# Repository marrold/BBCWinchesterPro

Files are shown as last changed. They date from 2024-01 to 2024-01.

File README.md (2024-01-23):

# BBCWinchesterPro

A PCB that combines a Raspberry Pi running [PiTubeDirect](https://github.com/hoglet67/PiTubeDirect) and a J.G Harston's [IDE Interface](https://mdfs.net/Info/Comp/BBC/IDE/), intended to emulate the 6502 2nd Processor and Winchester Hard Disk required to run a Level 3 Econet Fileserver on a BBC Micro Model B.

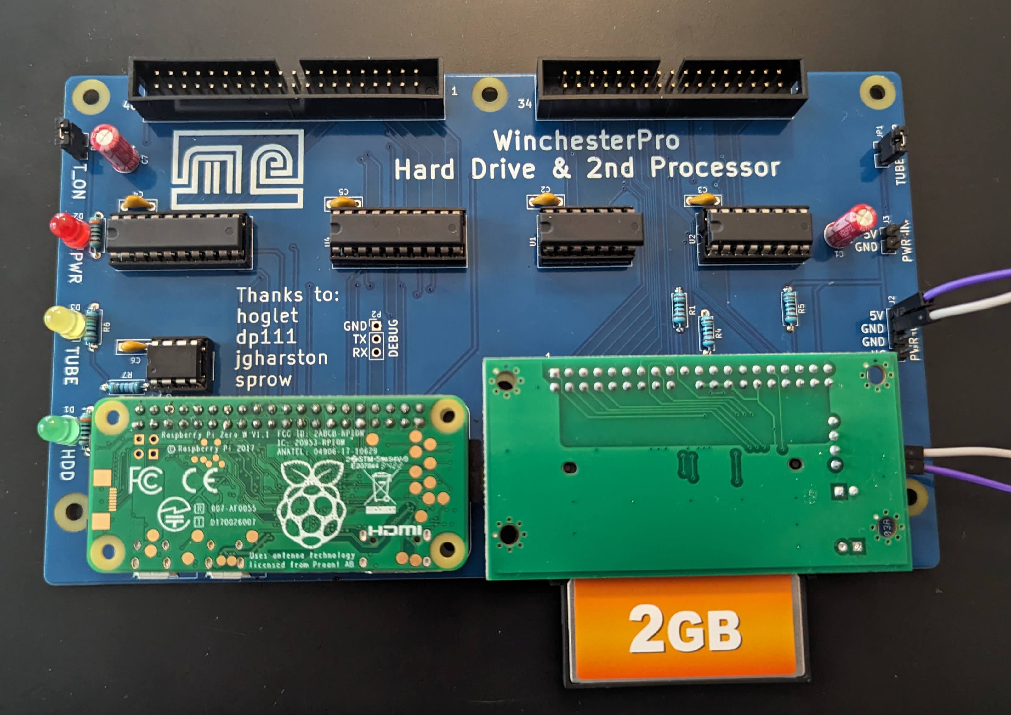
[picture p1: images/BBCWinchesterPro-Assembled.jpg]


The current revision was designed to test if the theory works rather than a finished product. The long term goal is to place it in a suitably 80's looking enclosure which will probably require some changes to the overall size and mounting holes but perhaps in the meantime the schematics and PCB will be useful to someone.

The schematic is included as a [PDF](Schematic.pdf)

## Whats the ATTiny MCU for?

PiTubeDirect *toggles* the Pi's onboard LED when the Tube is accessed, however I'd like an external LED to pulse with activity. The ATTiny detects a rising or falling edge and pulses the LED for 50ms.

To use this feature you'll need to program the ATTiny and use the [Indigo Alpha 4](https://github.com/hoglet67/PiTubeDirect/releases/tag/indigo-alpha4) revision of PiTubeDirect which supports re-mapping the activity to another GPIO.

Add the following to the end of `cmdline.txt`:
`bcm2708.disk_led_gpio=16`

This is somewhat experimental, the code is crude, and I'm not entirely sure if its detecting every edge when the Tube is at full tilt, but it makes the LED blink convincingly   so its good enough for my requirements.

If you don't want to bother with it, you can bridge pins 2 and 3 of the U5 footprint, indicated on the silkscreen.

## Usage

- It's *highly recommended* to use a 2GB CF Card as modified tools exist to deal with a disc this size
- For information on setting up and using PiTubeDirect, see the projects detailed [Wiki](https://github.com/hoglet67/PiTubeDirect/wiki)
- To use the IDE interface you'll need version [ADFS  v1.33](https://mdfs.net/System/ROMs/Filing/Disk/Acorn/ADFS133) which has been patched for IDE support.
- I also recommend using patched versions of [HDInit](https://mdfs.net/Info/Comp/BBC/IDE/HDInit) and [WFSInit](https://stardot.org.uk/forums/viewtopic.php?p=411297#p411297) that can handle larger discs.
- For instructions on formatting the CF card see the [Wiki](https://github.com/marrold/BBCWinchesterPro/wiki/Formatting-the-Hard-Disk)
- For instructions on setting up the Econet partition, also see the [Wiki](https://github.com/marrold/BBCWinchesterPro/wiki/Initialising-the-Disk-for-a-Level-3-Econet-Fileserver)

## Parts Required

- [PCI slot IDE to Compact Flash Adapter](https://www.amazon.co.uk/gp/product/B0913811PP)
- Raspberry Pi + SD Card
- 5x 0.1uF ceramic capacitors with a 5mm pitch
- 2x 22uF electrolytic capacitors with a 2mm pitch
- 3x 1k 1/4w resistors
- 3x LEDs and suitable 1/4w resistors
- 2x [SN74LVC245AN](http://d.digikey.com/dc/mn-w0iJh4uEE_bUitNCuXpPSTLmwSDrmPaa_ksuLmn07WQWvHI6vieAM8l8Rz71y9-o2iqNxD_lrRHs2f6p78UOWSMZi80Re0OX4QjTHXhzXzyCP1n-WYmlf5x2yjzHYfHzZC5O6tAVst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)
- 1x [SN74LS02N](http://d.digikey.com/dc/mn-w0iJh4uEE_bUitNCuXpPSTLmwSDrmPaa_ksuLmn07WQWvHI6vieAM8l8Rz71y9-o2iqNxD_lrRHs2f6p78bnTDQXV0_ONXEKM5iC55d-ZDkkt9n89zQITQIYKv5ImfzPp6AZ2aezEF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)
- 1x [SN74LS139AN](http://d.digikey.com/dc/mn-w0iJh4uEE_bUitNCuXpPSTLmwSDrmPaa_ksuLmn07WQWvHI6vieAM8l8Rz71y9-o2iqNxD_lrRHs2f6p78ZChZSCAtt8kdLK_f7oz0DTUWDhmkEZ-6cGHutOkHit2hcfdb0F0ck6e2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)
- 1x [ATTINY85-20PU](http://d.digikey.com/dc/mn-w0iJh4uEE_bUitNCuXpPSTLmwSDrmPaa_ksuLmn3wb489Ozp7P-auFeMYVOl116EiIEbZ38BDQy1OX_LrrLPV3Ec8LFvckgIt5WBiMOWBzA2AtKbyb9r8UKNGoR5mw2eYflZHiaYFx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)
- 2x 20 pin DIP sockets
- 1x 16 pin DIP socket
- 1x 14 pin DIP socket
- 1x 4 pin DIP socket
- 1x 40 Pin, 2.54 pitch Male Shrouded + Keyed connector
-  1x 34 Pin, 2.54 pitch  Male Shrouded + Keyed connector
- 1x 40 Pin, 2.54 pitch Female connector with key
- 1x 40 Pin, 2.54 pitch  Female connector without key. (Or get 2 of the above)
- 2.54 pitch male header pins - a few
- 2x Jumpers
- Nylon PCB standoffs - some

## Future improvements
- The Raspberry Pi SD card is blocked by the CF adapter, so upgrading PiTubeDirect requires removing the Pi entirely which isn't great. The Tube and IDE sections of the board should probably be swapped.
- The PCB was designed for a specific IDE to CompactFlash adapter which has resulted in the pin numbering being backwards, making it unsuitable for use with cables or other adapters. In a future revision I'd like to use a standard pin numbering for greater flexibility
- There's no power available on pin 20 of the IDE connector, which some CF adapters can utilise. In future revision it's probably sensible to make power available on this pin with a solder jumper to enable it.

## License

- The PCB is licensed under GPL 3.0
- The [PiTubeDirect](https://github.com/hoglet67/PiTubeDirect) interface schematic and firmware is licensed under GPL 3.0
- The [IDE interface](https://mdfs.net/Info/Comp/BBC/IDE/) was designed by J.G Harston and [sprow](http://www.sprow.co.uk/) and anyone is permitted to use the design with acknowledgement.

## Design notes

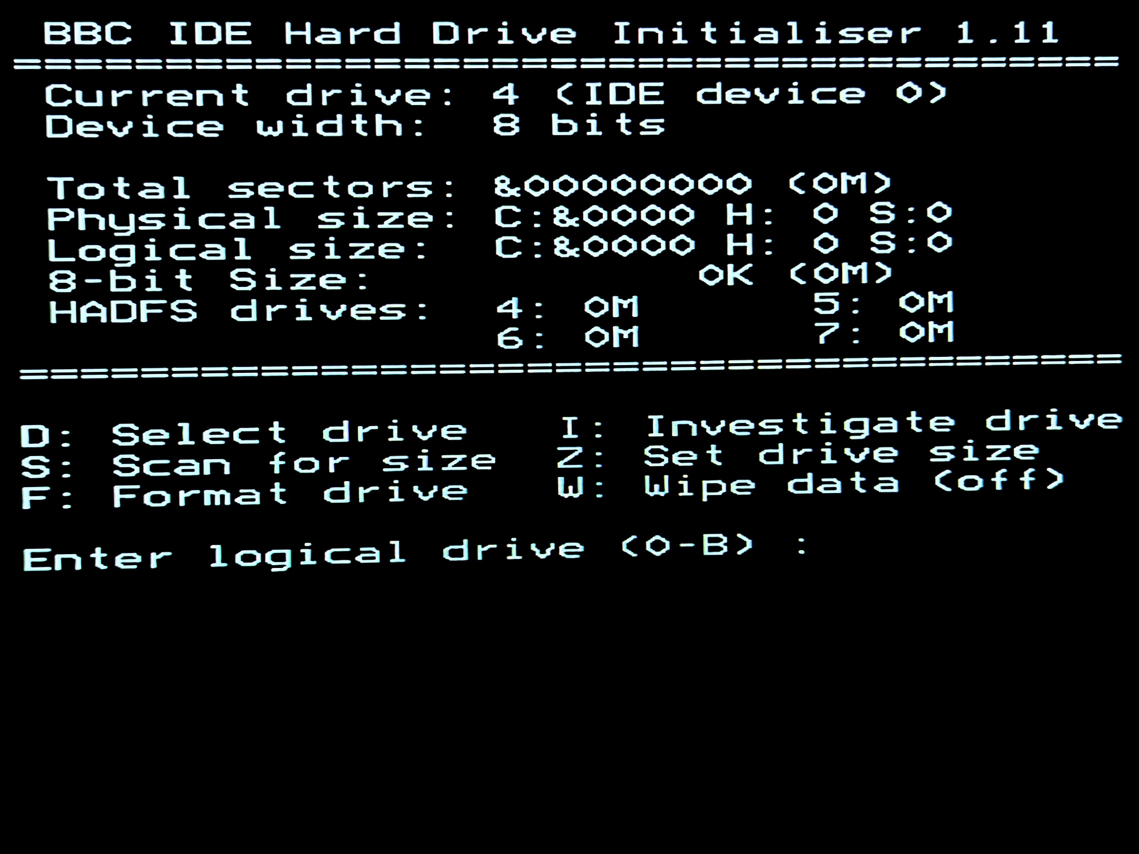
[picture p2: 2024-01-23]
images/HDINIT_DRIVE.jpg

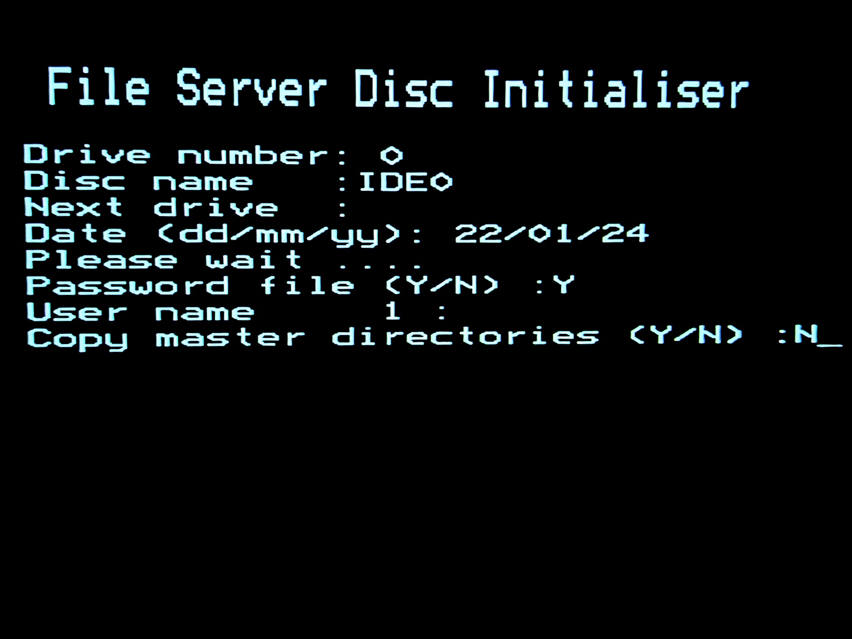
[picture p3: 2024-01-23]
images/WFSINIT_COPYMASTERDIRS.jpg

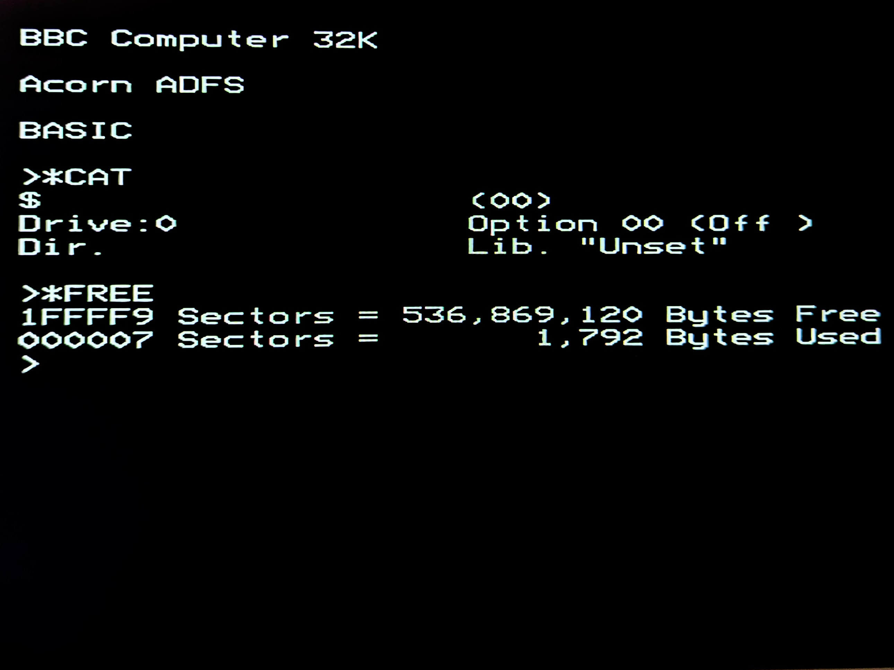
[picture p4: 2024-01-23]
images/HDINIT_FREE.jpg

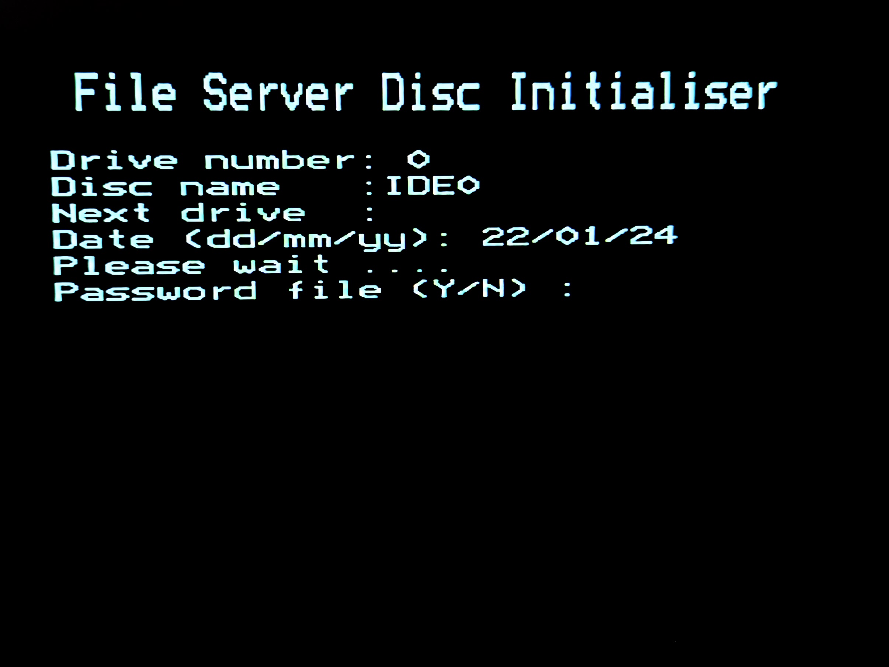
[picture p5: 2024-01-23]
images/WFSINIT_PASSWORDFILE.jpg

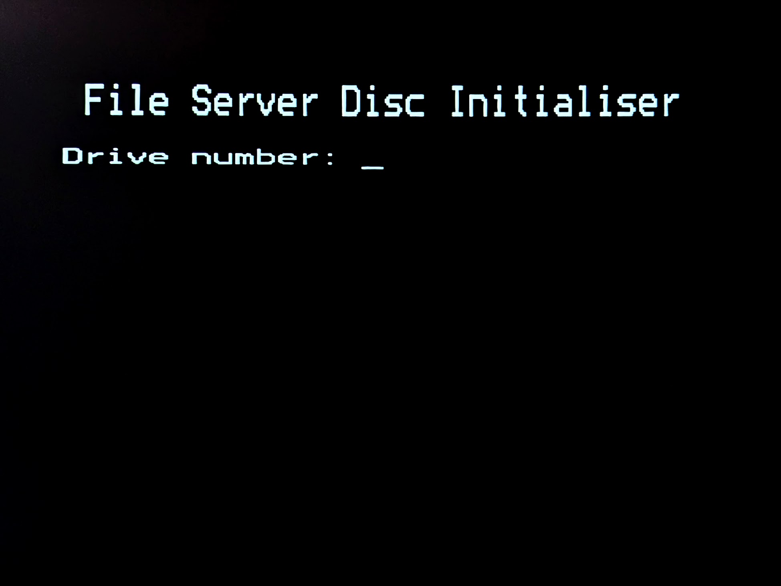
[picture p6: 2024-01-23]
images/WFSINIT_INITIAL.jpg

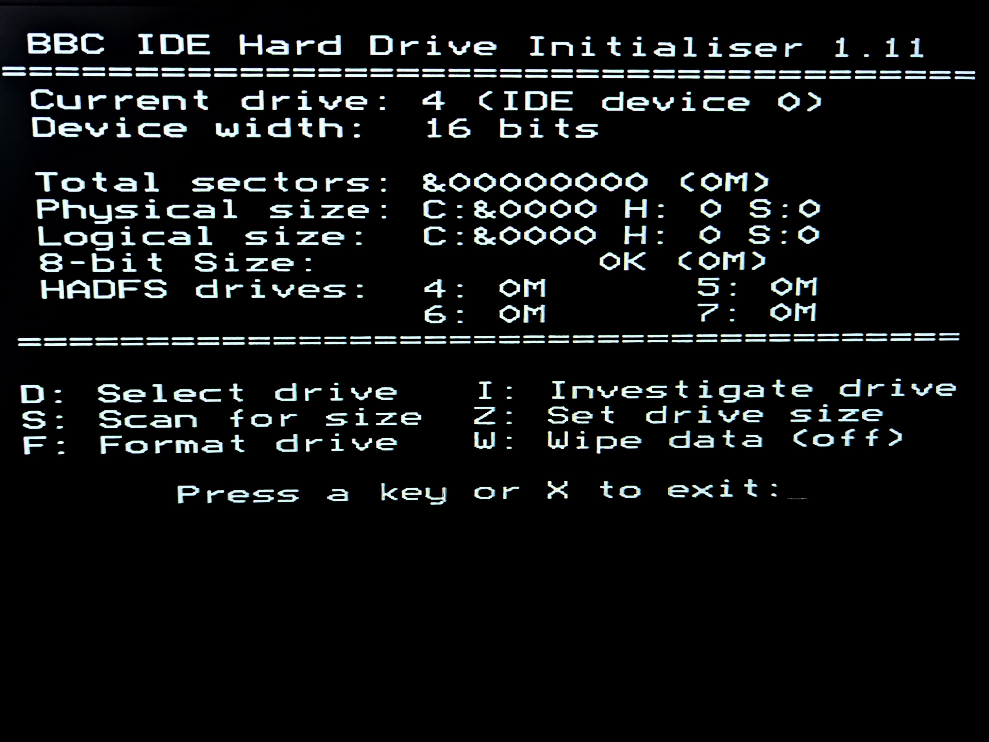
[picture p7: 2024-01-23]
images/HDINIT_INITIAL.jpg

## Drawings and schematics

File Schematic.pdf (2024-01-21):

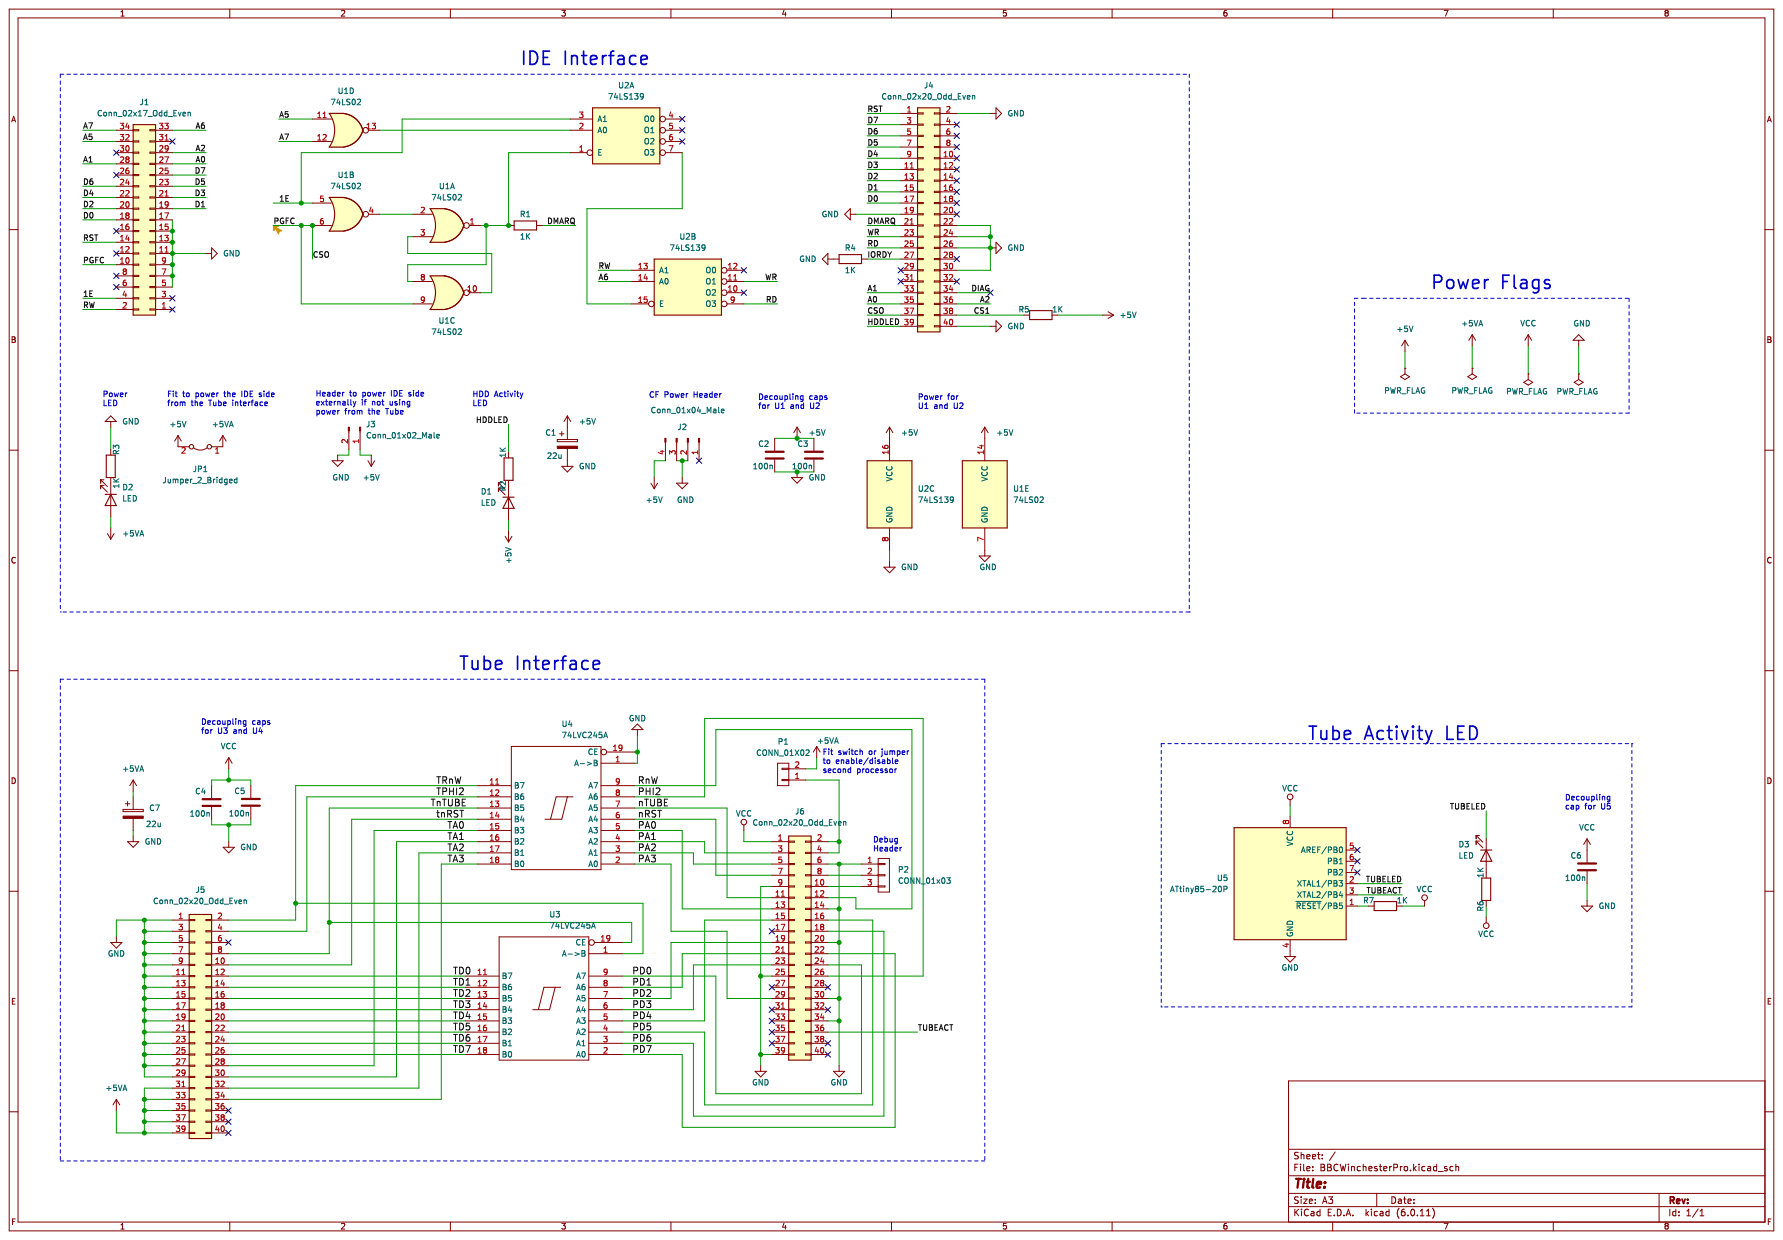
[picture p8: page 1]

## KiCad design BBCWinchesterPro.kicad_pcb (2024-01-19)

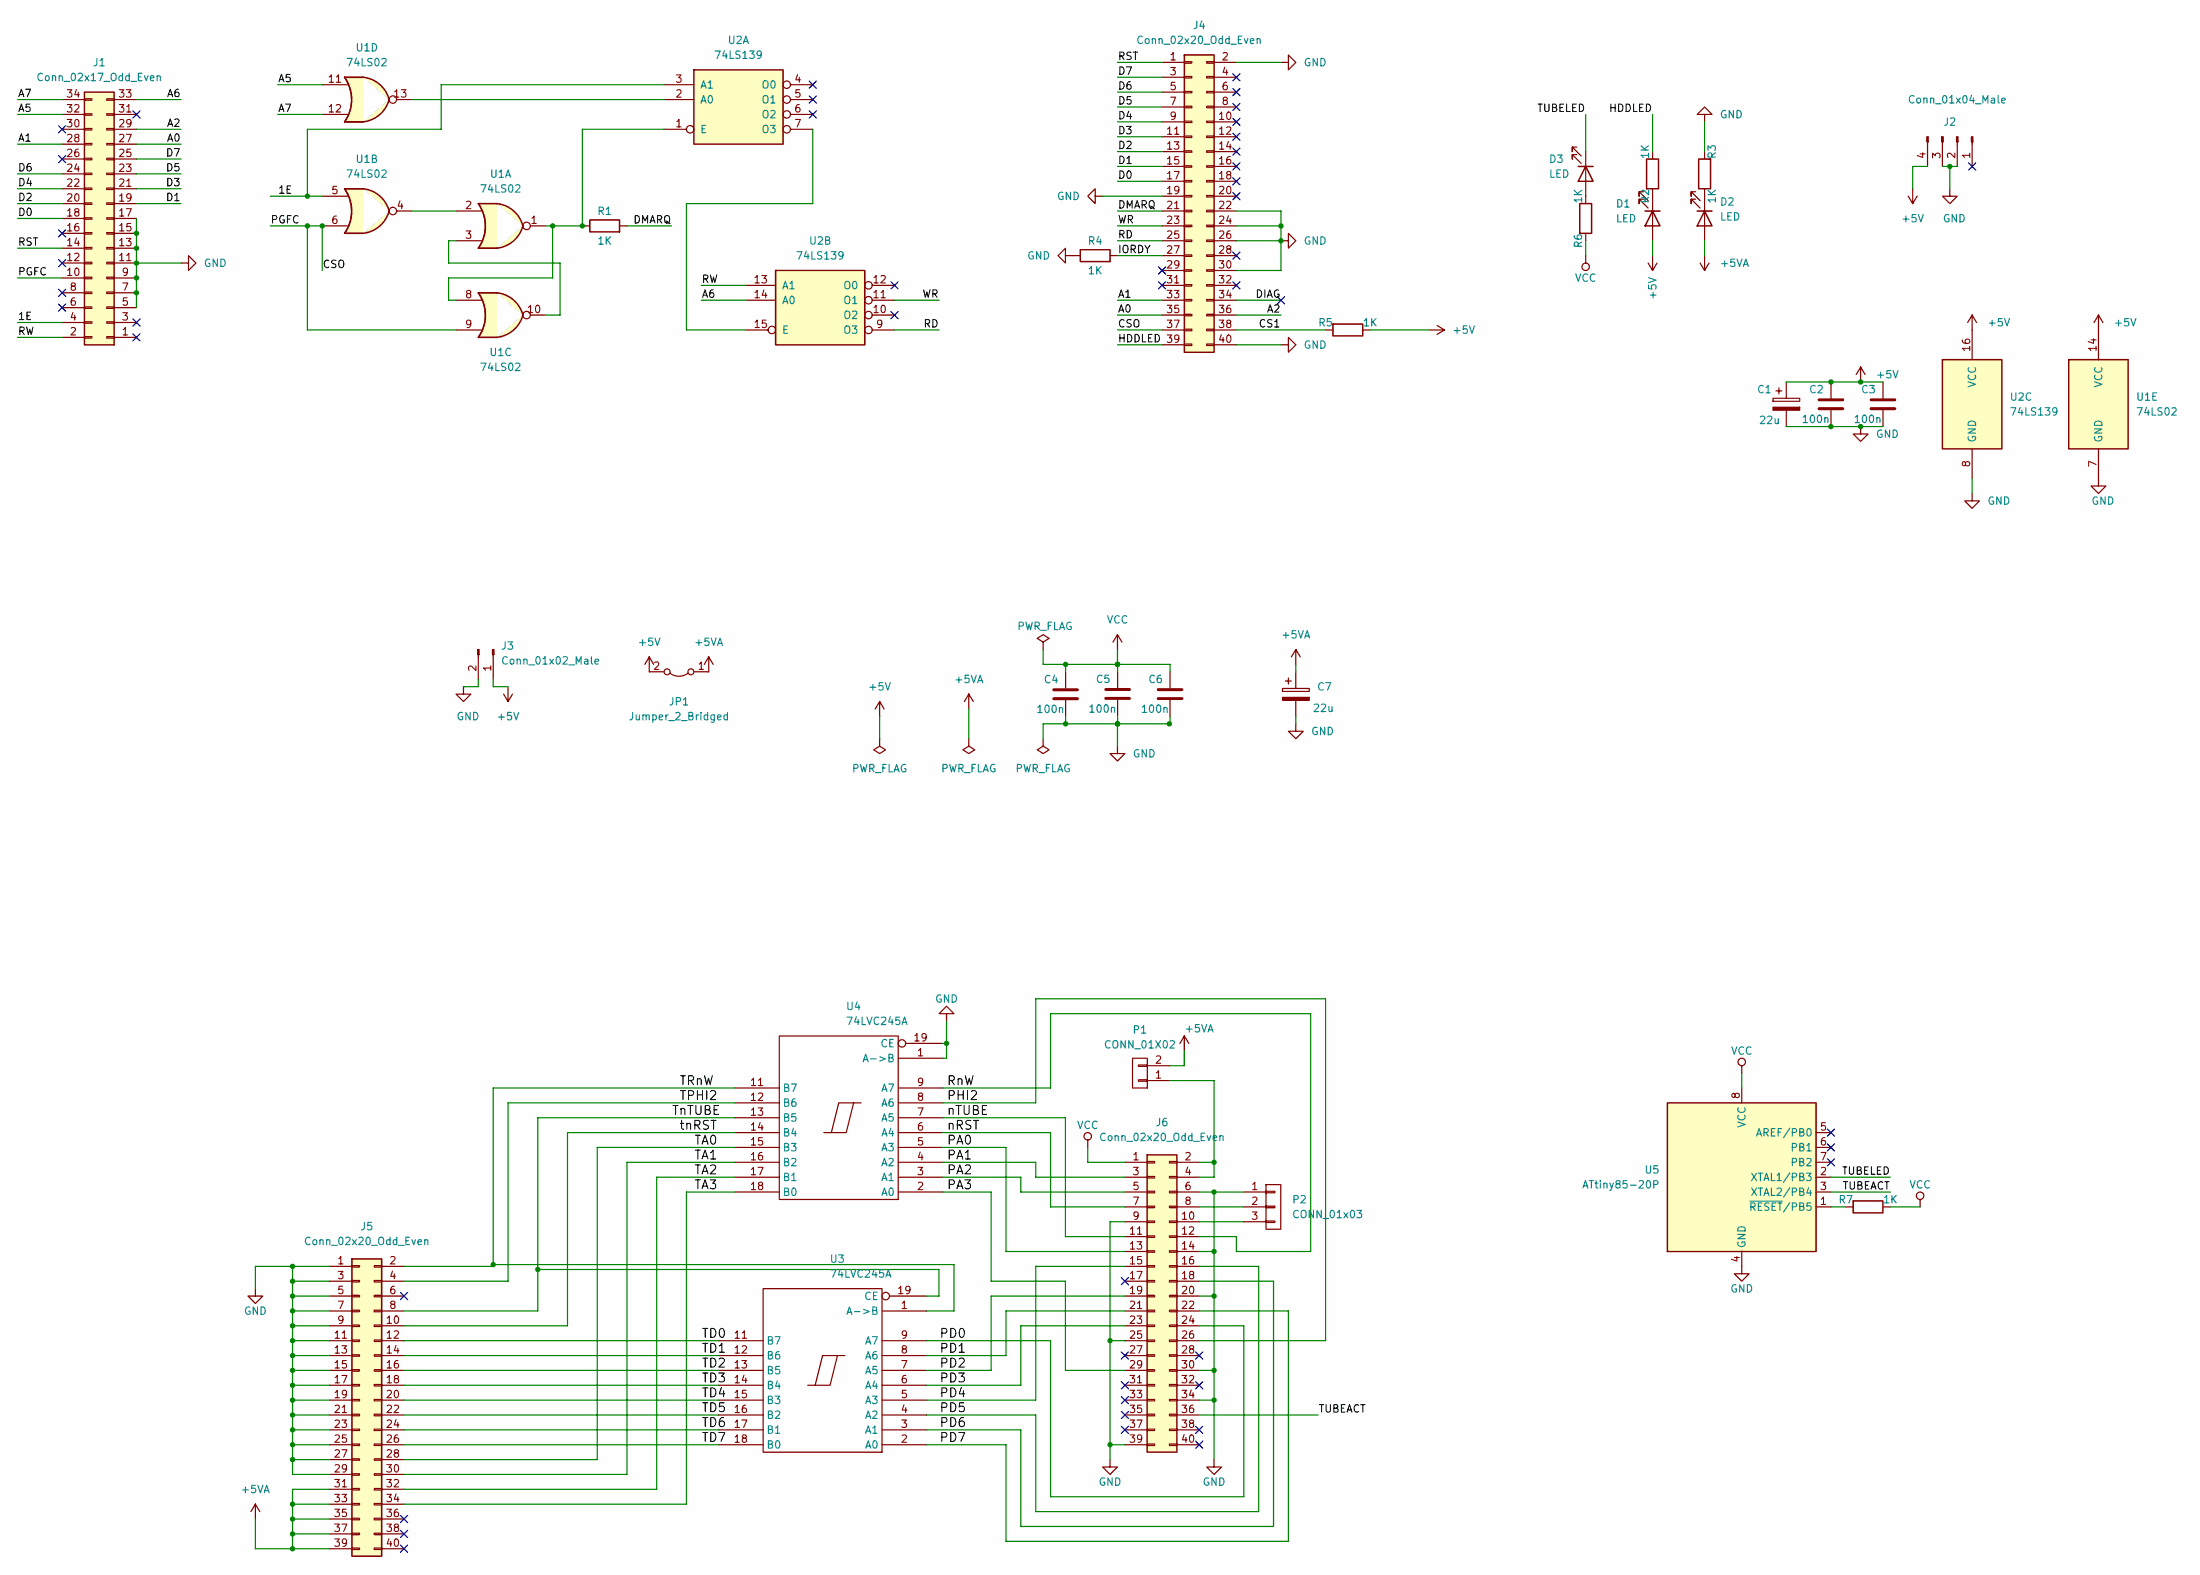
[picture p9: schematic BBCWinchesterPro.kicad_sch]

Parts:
C1, C7: 22u; CP_Radial_D5.0mm_P2.00mm
C2, C4, C5, C6: 100n; C_Rect_L7.0mm_W2.5mm_P5.00mm
C3: 100n; C_Rect_L7.0mm_W2.0mm_P5.00mm
D1, D2, D3: LED; PinHeader_1x02_P2.54mm_Vertical
J1: Conn_02x17_Odd_Even; IDC-Header_2x17_P2.54mm_Vertical
J2: Conn_01x04_Male; PinHeader_1x04_P2.54mm_Vertical
J3: Conn_01x02_Male; PinHeader_1x02_P2.54mm_Vertical
J4: Conn_02x20_Odd_Even; CF-Adapter
J5: Conn_02x20_Odd_Even; IDC-Header_2x20_P2.54mm_Vertical
J6: Conn_02x20_Odd_Even; Raspberry_Pi_Zero_Socketed_THT_FaceDown_MountingHoles
JP1: Jumper_2_Bridged; PinHeader_1x02_P2.54mm_Vertical
P1: CONN_01X02; PinHeader_1x02_P2.54mm_Vertical
P2: CONN_01x03; PinHeader_1x03_P2.54mm_Vertical
R1, R2, R3, R4, R5, R6, R7: 1K; R_Axial_DIN0207_L6.3mm_D2.5mm_P7.62mm_Horizontal
U1: 74LS02; DIP-14_W7.62mm_Socket
U2: 74LS139; DIP-16_W7.62mm_Socket
U3, U4: 74LVC245A; DIP-20_W7.62mm_Socket
U5: ATtiny85-20P; DIP-8_W7.62mm

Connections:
+5V: C1.1, C2.1, C3.1, D1.2 (A), J2.4, J3.1, JP1.2 (B), R5.1, U1.14 (VCC), U2.16 (VCC)
+5VA: C7.1, D2.2 (A), J5.31, J5.33, J5.35, J5.37, J5.39, JP1.1 (A), P1.2
/1E: J1.4, U1.5, U2.3 (A1)
/A0: J1.27, J4.35
/A1: J1.28, J4.33
/A2: J1.29, J4.36
/A5: J1.32, U1.11
/A6: J1.33, U2.14 (A0)
/A7: J1.34, U1.12
/CS1: J4.38, R5.2
/CSO: J1.10, J4.37, U1.6, U1.9
/D0: J1.18, J4.17
/D1: J1.19, J4.15
/D2: J1.20, J4.13
/D3: J1.21, J4.11
/D4: J1.22, J4.9
/D5: J1.23, J4.7
/D6: J1.24, J4.5
/D7: J1.25, J4.3
/DIAG: J4.34
/DMARQ: J4.21, R1.2
/HDDLED: J4.39, R2.1
/IORDY: J4.27, R4.2
/PA0: J6.13, U4.5 (A3)
/PA1: J6.3, U4.4 (A2)
/PA2: J6.5, U4.3 (A1)
/PA3: J6.29, U4.2 (A0)
/PD0: J6.24, U3.9 (A7)
/PD1: J6.21, U3.8 (A6)
/PD2: J6.19, U3.7 (A5)
/PD3: J6.23, U3.6 (A4)
/PD4: J6.15, U3.5 (A3)
/PD5: J6.16, U3.4 (A2)
/PD6: J6.18, U3.3 (A1)
/PD7: J6.22, U3.2 (A0)
/PHI2: J6.26, U4.8 (A6)
/RD: J4.25, U2.9 (O3)
/RST: J1.14, J4.1
/RW: J1.2, U2.13 (A1)
/RnW: J6.12, U4.9 (A7)
/TA0: J5.28, U4.15 (B3)
/TA1: J5.30, U4.16 (B2)
/TA2: J5.32, U4.17 (B1)
/TA3: J5.34, U4.18 (B0)
/TD0: J5.12, U3.11 (B7)
/TD1: J5.14, U3.12 (B6)
/TD2: J5.16, U3.13 (B5)
/TD3: J5.18, U3.14 (B4)
/TD4: J5.20, U3.15 (B3)
/TD5: J5.22, U3.16 (B2)
/TD6: J5.24, U3.17 (B1)
/TD7: J5.26, U3.18 (B0)
/TPHI2: J5.4, U4.12 (B6)
/TRnW: J5.2, U3.1 (A->B), U4.11 (B7)
/TUBEACT: J6.36, U5.3 (XTAL2/PB4)
/TUBELED: D3.1 (K), U5.2 (XTAL1/PB3)
/TnTUBE: J5.8, U3.19 (CE), U4.13 (B5)
/WR: J4.23, U2.11 (O1)
/nRST: J6.7, U4.6 (A4)
/nTUBE: J6.11, U4.7 (A5)
/tnRST: J5.10, U4.14 (B4)
GND: C1.2, C2.2, C3.2, C4.2, C5.2, C6.2, C7.2, J1.5, J1.7, J1.9, J1.11, J1.13, J1.15, J1.17, J2.2, J2.3, J3.2, J4.2, J4.19, J4.22, J4.24, J4.26, J4.30, J4.40, J5.1, J5.3, J5.5, J5.7, J5.9, J5.11, J5.13, J5.15, J5.17, J5.19, J5.21, J5.23, J5.25, J5.27, J5.29, J6.6, J6.9, J6.14, J6.20, J6.25, J6.30, J6.34, J6.39, P2.1, R3.2, R4.1, U1.7 (GND), U2.8 (GND), U3.10 (GND), U4.1 (A->B), U4.10 (GND), U4.19 (CE), U5.4 (GND)
unnamed: D1.1 (K), R2.2
unnamed: D2.1 (K), R3.1
unnamed: D3.2 (A), R6.1
unnamed: J6.2, J6.4, P1.1
unnamed: J6.8, P2.2
unnamed: J6.10, P2.3
unnamed: R1.1, U1.1, U1.8, U2.1 (E)
unnamed: U1.2, U1.4
unnamed: U1.3, U1.10
unnamed: U1.13, U2.2 (A0)
unnamed: U2.7 (O3), U2.15 (E)
unnamed: R7.2, U5.1 (~RESET/PB5)
VCC: C4.1, C5.1, C6.1, J6.1, R6.2, R7.1, U3.20 (VCC), U4.20 (VCC), U5.8 (VCC)

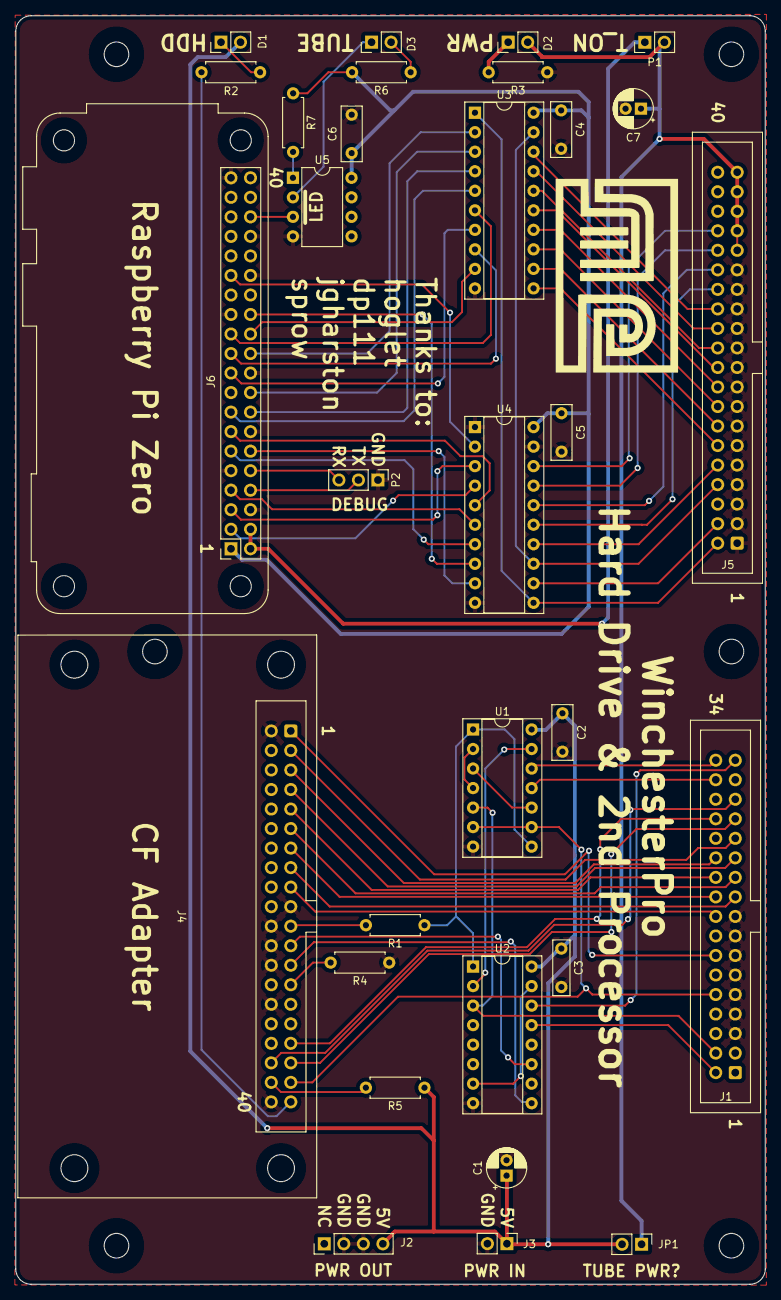
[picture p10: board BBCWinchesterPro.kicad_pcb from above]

Board: 2 copper layers, 97.5 x 165.0 mm, 31 parts (0 on the bottom side), 74 nets.

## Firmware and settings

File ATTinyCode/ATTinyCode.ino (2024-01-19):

const int ledPin = 3; // LED connected to physical pin 2
const int inputPin = 4; // Input pin on physical pin 3

bool lastInputState = LOW;    // Last stable state of the input pin
bool lastReadState = LOW;     // Last read state of the input pin
unsigned long ledOffTime = 0;

void setup() {
  pinMode(ledPin, OUTPUT);      // Set the LED pin as output
  digitalWrite(ledPin, HIGH);
  pinMode(inputPin, INPUT_PULLUP); // Set the input pin as input with pull-up resistor
  lastInputState = digitalRead(inputPin);
  lastReadState = lastInputState;
}

void loop() {
  bool currentReadState = digitalRead(inputPin);

  // Check if the read state is different from the last read state
  if (currentReadState != lastReadState) {
    lastReadState = currentReadState; // Update the last read state
  }

  // Check if the stable input state is different from the last stable state
  if (currentReadState != lastInputState) {
    lastInputState = currentReadState; // Update the last stable input state

    // Edge detected
    digitalWrite(ledPin, LOW); // Turn on the LED
    ledOffTime = millis() + 50; // Set the time to turn off LED
  }

  // Turn off the LED after the delay
  if (millis() >= ledOffTime && digitalRead(ledPin) == LOW) {
    digitalWrite(ledPin, HIGH);
  }
}

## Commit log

2024-01-03 Fix DRC
    [BBCWinchesterPro-B_Cu.gbr, BBCWinchesterPro-B_Mask.gbr, BBCWinchesterPro-B_Paste.gbr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]
2024-01-19 Add ATTiny code and remove license from silkscreen
    [BBCWinchesterPro-B_Cu.gbr, BBCWinchesterPro-B_Mask.gbr, BBCWinchesterPro-B_Paste.gbr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]
2024-01-21 Annotate schematic and export as PDF
    [BBCWinchesterPro.kicad_sch]
